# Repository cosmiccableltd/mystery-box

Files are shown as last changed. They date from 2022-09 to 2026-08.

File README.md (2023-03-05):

# Mystery Box

## About
The Mystery Box is a small PCB which provides power ports for various devices to indicate a ringing phone and drive POE devices.
It was designed by [Cosmic Cable Ltd.](http://cosmic.cable.limited) to be used for self-made telephone booths. 

PCB_Overview

## Ports
| Port Name | Function | Usage |
| --- | --- | ----- |
| J1 | [POE](https://en.wikipedia.org/wiki/Power_over_Ethernet) Port | POE powered network device |
| J2 | LAN Port | Connection to external network |
| J3 | Analogue Telephone Port | Connection to external analogue network |
| J4 | Analogue Telephone Port | Connection to analogue telephone |
| X1-1 | +12V | |
| X1-2 |  GND (switched) | swichted on ringing phone line |
| X1-3 | +12V | |
| X1-4 |  GND | |
| X1-5 | +12V | |
| X1-6 |  GND | |
| X1-7 | +12V | |
| X1-8 |  GND | |

## Known Issues
We experienced that the PMV20EN Q2 Mosfet might die from to high current.
It should be changed to something which can handle more current or otherwise it must be ensured that the outgoing power is limited.

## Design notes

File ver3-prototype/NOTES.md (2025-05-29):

- esp32 S3 Zero 
- 12V Buchse 6,3/3.0 + Terminal
- 5-10 feststrom ausgang +
- 5-10 feststrom ausgang -
- 3 geschaltete ausgänge für LED mit N-Kanal-Mosfet (freilaufdiode, pull-down widerstand) IRLZ44N
- DMX ausgang Terminal
- Neopixel ausgang
- POE/RJ45
- optional sicherung am eingang, gesonderter ausgang für o2 Box, Spannungsteiler an ESP für Meldung

- große schraubterminals ohne stecker

pins

DMX 				2x GPIO
Geschaltete Ausgänge 		3x GPIO
Neopixel			2x GPIO

rj45
sicherung + ausgänge + spannungsteiler

länge 4.9mm
breite 6mm

https://learn.adafruit.com/circuitpython-with-esp32-quick-start/command-line-esptool
https://circuitpython.org/board/waveshare_esp32_s3_zero/

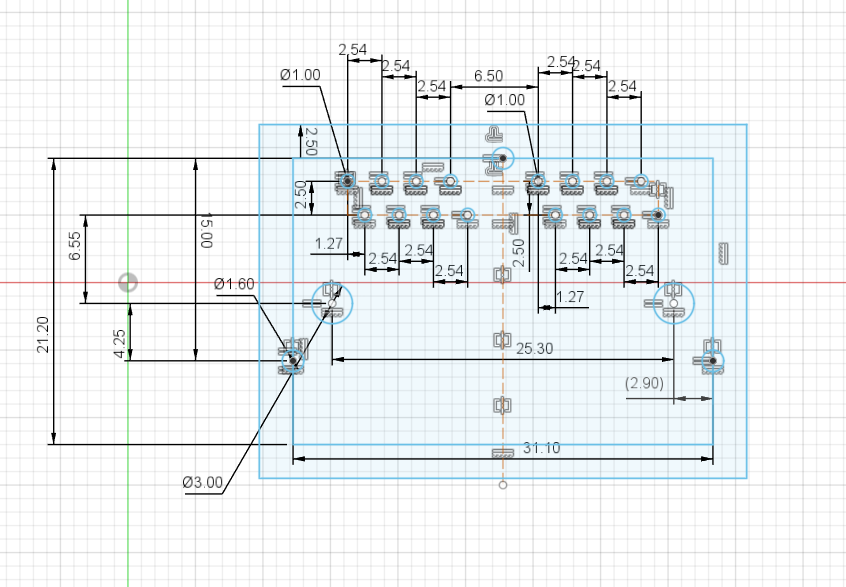
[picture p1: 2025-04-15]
ver3-prototype/Screenshot 2025-04-15 212653.png

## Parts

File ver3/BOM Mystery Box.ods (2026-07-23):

Name | Anzahl | Vorhanden | Bemerkungen | Link
5V Buck Converter | 1 |  |  | https://de.aliexpress.com/item/1005005296570391.html
24V Boost Converter | 1 |  |  | https://de.aliexpress.com/item/1005006381432341.html
Kerko 100nf | 2
Diode groß | 3 |  | Pitch 10,16
Diode klein | 1 |  | Pitch 7,62
Schraubterminal 2-Fach | 17 |  |  | https://de.aliexpress.com/item/1005009002216100.html
Schraubterminal 3-Fach | 4 |  |  | https://de.aliexpress.com/item/1005009002216100.html
XLR-Buchse Female | 1 |  |  | https://de.aliexpress.com/item/1005009831794833.html
ESP32 S3 Zero | 1 |  |  | https://de.aliexpress.com/item/1005007948911104.html
Pin Header | 25
Pin Header Buchse 1x9 | 2 |  |  | https://de.aliexpress.com/item/32970948352.html
Barrel Jack | 1 |  | auf alten platinen | https://www.digikey.de/de/products/detail/same-sky-formerly-cui-devices/PJ-050BH/1644584
RJ45 Doppelbuchse | 1 |  |  | https://de.aliexpress.com/item/1005007077598876.html
LED Blau 3mm | 1
LED Grün 3mm | 1
Neopixel WS2812B | 3
MOSFET IRLZ44N | 3
Widerstand 100 Ohm | 3
Widerstand 1k Ohm | 3
Widerstand 10k Ohm | 3
Smart Switch BV1HD090FJ-C | 1 |  | auf alten platinen | https://www.rohm.de/products/power-management/ipds/smart-high-side-switch-ics/bv1hd090fj-c-product
DMX THVD1400D | 1 |  |  | https://de.aliexpress.com/item/1005009482834248.html
Zylinkerkopfschraube M3x4 | 2
Senkkopfschraube M3x12 | 4
Gehäuse | 1
Deckel | 1
USB-C Kabel | 1 |  |  | https://de.aliexpress.com/item/1005003311183241.html

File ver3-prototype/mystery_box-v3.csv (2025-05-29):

Reference | Value | Footprint | Datasheet | Qty | Qty +ACo- 5
+ACI-12v+AF8-input+AF8-terminal1 | J8 | J9 | J10 | J11 | J12 | J13 | J14 | J15 | J16 | J17 | neopixel+AF8-out1 | neopixel+AF8-pwr1 | switched+AF8-output+AF8-01 | switched+AF8-output+AF8-02 | switched+AF8-output+AF8-03+ACI- | Screw+AF8-Terminal+AF8-01x02 | TerminalBlock:TerminalBlock+AF8-MaiXu+AF8-MX126+AC0-5.0+AC0-02P+AF8-1x02+AF8-P5.00mm | +AH4- | 16 | 80
+ACI-D1 | D2 | D3+ACI- | D | Diode+AF8-THT:D+AF8-DO+AC0-15+AF8-P10.16mm+AF8-Horizontal | +AH4- | 3 | 15
dmx+AF8-out1 | DMX Out | TerminalBlock:TerminalBlock+AF8-MaiXu+AF8-MX126+AC0-5.0+AC0-03P+AF8-1x03+AF8-P5.00mm | +AH4- | 1 | 5
ESP32+AF8-S3 | +AH4- | eigene+AF8-footprints:ESP32+AC0-S3+AC0-Zero |  | 1 | 5
+ACI-J1 | J2 | J3 | J4+ACI- | Conn+AF8-01x02+AF8-Pin | Connector+AF8-PinHeader+AF8-1.00mm:PinHeader+AF8-1x02+AF8-P1.00mm+AF8-Vertical | +AH4- | 4 | 20
J18 | Barrel+AF8-Jack+AF8-MountingPin | eigene+AF8-footprints:CUI+AF8-PJ+AC0-050BH | +AH4- | 1 | 5
J20 | rj45+AC0-CC+AC0-X2+AC0-Aliexpress | eigene+AF8-footprints:RJ45+AF8-X2+AF8-CC+AF8-Aliexpress | +AH4- | 1 | 5
+ACI-Q1 | Q2 | Q3+ACI- | IRLZ44N | Package+AF8-TO+AF8-SOT+AF8-THT:TO+AC0-220+AC0-3+AF8-Vertical | http://www.irf.com/product+AC0-info/datasheets/data/irlz44n.pdf | 3 | 15
+ACI-R1 | R2 | R3+ACI- | R | Resistor+AF8-THT:R+AF8-Axial+AF8-DIN0207+AF8-L6.3mm+AF8-D2.5mm+AF8-P10.16mm+AF8-Horizontal | +AH4- | 3 | 15
U1 | +AH4- | eigene+AF8-footprints:level+AF8-shifter |  | 1 | 5
U2 | MAX485E | eigene+AF8-footprints:max845 modul | https://datasheets.maximintegrated.com/en/ds/MAX1487E+AC0-MAX491E.pdf | 1 | 5
U3 | +AH4- | Package+AF8-SO:SOIC+AC0-8+AF8-3.9x4.9mm+AF8-P1.27mm |  | 1 | 5

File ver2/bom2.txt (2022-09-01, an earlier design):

Partlist

Exported from ver2.brd at 3/28/17 8:25 PM

EAGLE Version 6.6.0 Copyright (c) 1988-2014 CadSoft

Assembly variant: 

Part     Value              Package      Library                 Position (mil)        Orientation

C1       100n 25v           C0805K       rcl                     (918.92495 1325.91216) R0
C4       100n 25v           C0805K       rcl                     (1123.10925 1524.35015) R0
C7       100n 25v           C0805K       rcl                     (783.97183 578.81041) R0

C2       1u 50V             C0805K       rcl                     (968.92495 1525.91216) R0

C3       2u2 50V            C1206K       rcl                     (718.92495 1475.91216) R270
C9       2u2 50V            C1206K       rcl                     (2354.87709 852.59252) R0

C5       10u 16V            C0805K       rcl                     (1418.92495 1075.91216) R180

C6       1u 630V DC         C275-205X316 rcl                     (3425.6122 1598.19808) R270

C10      470u/25V           E3,5-8       rcl                     (1231.07333 707.17938) R180          REICHELT RAD FR 1.000/16

D1       MBRS360            SMC          diode                   (1382.47478 1352.99139) R270         REICHELT MBRS 360 SMD

D2       BZX84CSMD 16V      TO236        diode                   (1924.0689 945.49163) R180

D3       BZX84CSMD          TO236        diode                   (3235.41228 900.07616) R90
D4       BZX84CSMD 20V      TO236        diode                   (3448.09055 902.69254) R270

D5       1N4004             DO41-10      diode                   (3357.73216 735.03543) R180          REICHELT 1N 4007
D6       1N4004             DO41-10      diode                   (3356.86516 611.26833) R0
D7       1N4004             DO41-10      diode                   (3357.72527 493.71395) R180
D8       1N4007             DO41-10      diode                   (3356.79134 353.74508) R0

J1                          215877-4     con-amp                 (147.49422 1512.76956) R270          REICHELT MEBP 8-8S
J2                          215877-4     con-amp                 (147.49422 862.76956) R270
J3                          215876-6     con-amp                 (4264.30106 1402.72625) R90          REICHELT MEBP 6-4S
J4                          215876-6     con-amp                 (4268.68233 850.98068) R90

L1       PIS4728 10u        PIS4728      pis4728                 (1818.92495 1375.91216) R0

LED1                        LED5MM       led                     (852.84584 153.52793) R0             REICHELT LED 5-39000 GN

OK1      4N27M              DIL06        optocoupler             (2731.15527 1140.78962) R90          REICHELT 4N27
PAD1                        3,17/1,3     wirepad                 (2556.01686 146.25234) R0
PAD2                        3,17/1,3     wirepad                 (2395.2201 146.67249) R0

Q1       BSS84              SOT23        transistor-small-signal (2246.26981 1145.81348) R9           REICHELT BSS 84P SMD

Q2       PMV20EN            SOT23        pmv20en                 (2117.93406 1034.52621) R180
Q3       PMV20EN            SOT23        pmv20en                 (782.48376 882.83108) R0
Q4       PMV20EN            SOT23        pmv20en                 (1553.82234 947.54811) R90

R1       267k               R0603        rcl                     (818.92495 1425.91216) R90
R2       R05 RL12T.05JCT-ND R0805        rcl                     (1217.36307 1352.48228) R90
R3       37k4               R0603        rcl                     (1068.92495 1225.91216) R180
R4       9k76               R0603        rcl                     (1068.92495 1325.91216) R0
R5       1M                 R0805        rcl                     (3881.24779 1750.36602) R270
R6       2k2                R1206        rcl                     (3619.24397 902.47527) R0
R7       1M                 R0805        rcl                     (2389.06176 1028.62377) R0
R8       100k               R0805        rcl                     (2379.37758 1148.46752) R90
R9       1k                 R1206        rcl                     (2202.75197 1294.39062) R270
R10      430                R1206        rcl                     (944.13595 701.07505) R90
R11      100                R0603        rcl                     (677.84252 700.66708) R90
R13      1k                 R0805        rcl                     (2239.16265 1002.69968) R90
R14      10k                R0805        rcl                     (1777.88423 925.61368) R90

U$1      LM25011            HVSSOP-10    lm25011                 (1018.92495 1425.91216) R270
U$2      LM5050             SOT-23-6     lm5050                  (782.45042 706.9562)  R0
X1       AKL382-8           ALK382-8     akl382                  (1660.62992 -157.48031) MR0      REICHELT AKL 382 08

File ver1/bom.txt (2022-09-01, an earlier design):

Reichelt:

Count   Art-NO			Comment		Parts
! 3	X7R-G0805 100N		50V rated	C1,C4,C7
! 1	X7R-G0805 1,0/50	50V rated	C2
! 1	X7R-G1206 2,2/50	50V rated	C3
! 1	X5R-G0805 10/16		16V rated	C5
! 1	MKP4-630 1,0µ		630V rated	C6
! 1	TAJ 7343 47/25		25V Tantal	C9
! 1	RAD FC 470/25		25V Elko	C10
! 1	MBRS 360 SMD		Shottky Diode	D1
! 4	1N 4007			Rect Diode	D5-D8
! 2	MEBP 8-8S		RJ45 Buchse	J1,J2
! 2	MEBP 6-4S		RJ11 Buchse	J3,J4
! 1	L-PIS4728 10µ		Spule		L1
! 1	LED 5-39000 GN		LED Gruen	LED1
! 1	4N 27			Optokoppler	OK1
! 1	BSS 84P SMD		PMOS		Q1
! 1	RND 1206 1 2,2K		Widerstand	R6
! 1	RND 1206 1 1,0K		Widerstand	R9
! 1	RND 1206 1 470		Widerstand	R10
! 2	RND 0805 1 1M		Widerstand	R5,R7
! 1	RND 0805 1 100K		Widerstand	R8
! 1	RND 0805 1 1,0K		Widerstand	R13
! 1	RND 0805 1 10k		Widerstand	R14
! 1	RND 0603 1 100		Widerstand	R11
! 1	AKL 382-08		Wannenbuchse	X1
! 1	AKL 369-08		Wannenstecker	X1
! 1	LM 5050MK-1		Diode Ctrl	U$2
! 1	LUM XNES 250		Hohlstecker
! 1	LA 210-5		Zwillingslitze
! 1	1591CFLBK		Gehaeuse

Digikey:
! 1	LM25011 U$1
! 2       BZX84CSMD 20V D3,D4 BZX84C20LT1GOSCT-ND
! 1	  BZX84CSMD 16V D2    BZX84C16FSCT-ND
! 3       PMV20EN Q2,Q3,Q4
! 1       267k               R0603        R1
! 1       37k4               R0603        R3
! 1       9k76               R0603        R4
! 1       R05 RL12T.05JCT-ND R0805        R2

+4 Hohlstecker, Wannenstecker, Gehaeuse
-2 PAD

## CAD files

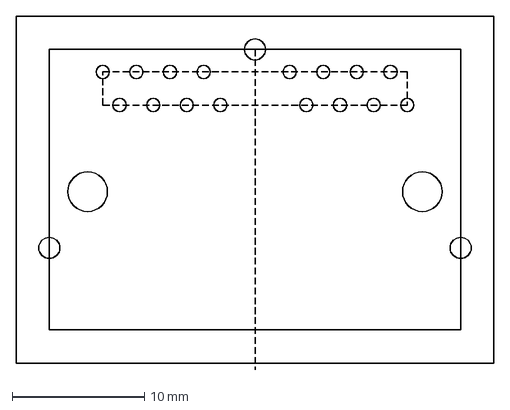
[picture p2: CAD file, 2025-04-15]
ver3-prototype/rj45-footprint.dxf
36.1 x 26.7 mm

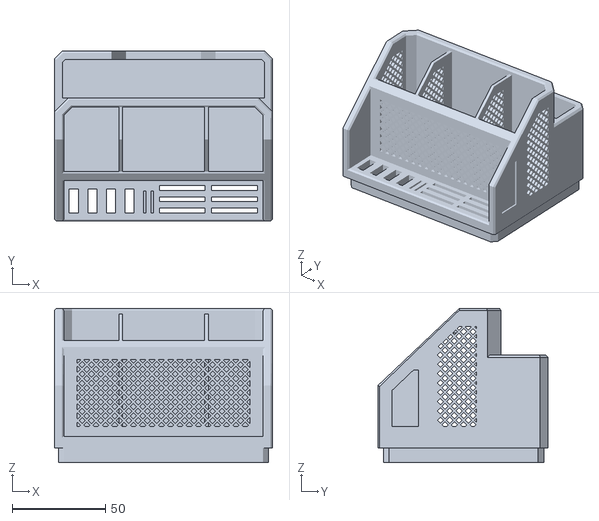
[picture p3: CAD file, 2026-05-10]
ver3/Pencil_Organizer_Wide_Remix.stl
117.0 x 91.5 x 82.7

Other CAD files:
ver3-prototype/rj45-footprint v1.f3d

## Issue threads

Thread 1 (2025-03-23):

Provide schematic (and maybe board?) as PDF.

dronus, 2025-03-23:
Would be cool to have a look into the current state right here without having to download the schematics and run KiCad on them.

Especially useful as KiCad has a quite strict version policy - to open the schematics, a quite fresh version from the last month is needed.

Closed 2025-03-27.

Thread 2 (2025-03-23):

MCU power supply?

dronus, 2025-03-23:
On https://github.com/cosmiccableltd/mystery-box/tree/main/ver3/mystery_box-v3.kicad_sch , the MCU power supply seems missing. The on-board regulators of most ESP32 breakouts don't handle 12V well, so an external regulator (linear or buck) would probably be needed.

Also passing POE power unregulated to the outputs needs guarantees about the provided POE voltage and current capability.

benibr, 2025-03-27:
The idea was to use the power provided via USB from the o2-box for the ESP32, which should be enough.

benibr, 2025-03-27:
Regarding POE: yes this is dangerous POE but the old nanostations expect voltage to "just be there" on the specified lines. They cannot negotiate power supply with 802.3af or similar.
Also this way it's compliant (lol) with the version 2 of the mystery box

Closed 2025-05-28.

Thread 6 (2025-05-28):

Smart switch

benibr, 2025-05-28:
Smart switch should be reevaluated after prototype testing.

If still used:

- [ ] ensure copper connection to OUT pin is thick enough
- [ ] add missing label to Silk Screen

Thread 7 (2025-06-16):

Necessary Improvements after first soldering

benibr, 2025-06-16:
- [ ] Freilaufdioden zu groß für den Platz auf der Plantine. Vorschlag: kleiner Dioden nehmen
- [ ] J1-4 sind viel zu klein
- [ ] USB-C Buchse hat keinen Platz für Stecker
- [ ] Lötpads von Smartswitch ggf. breiter machen zum einfacheren Löten
- [ ] Pinabstand von Levelshifter, komplett falsch, lol
- [ ] Widerstände haben keine Werte
- [ ] Schraubterminal direkt nebeneinander platzieren, damit diese miteinander verbunden werden können (Stabilität)
- [ ] wir haben 10x IRLZ44N gekauft und 5x IRFZ44N. Ist das ein Unterschied?
- [ ] Pins von RJ45 Stecker sind spiegelverkehrt
- [ ] DMX Out 3er Terminal wurde nicht bestellt
- [ ] Clearence beachten zwische   R3 und Verbindung Max485 <-> ESP

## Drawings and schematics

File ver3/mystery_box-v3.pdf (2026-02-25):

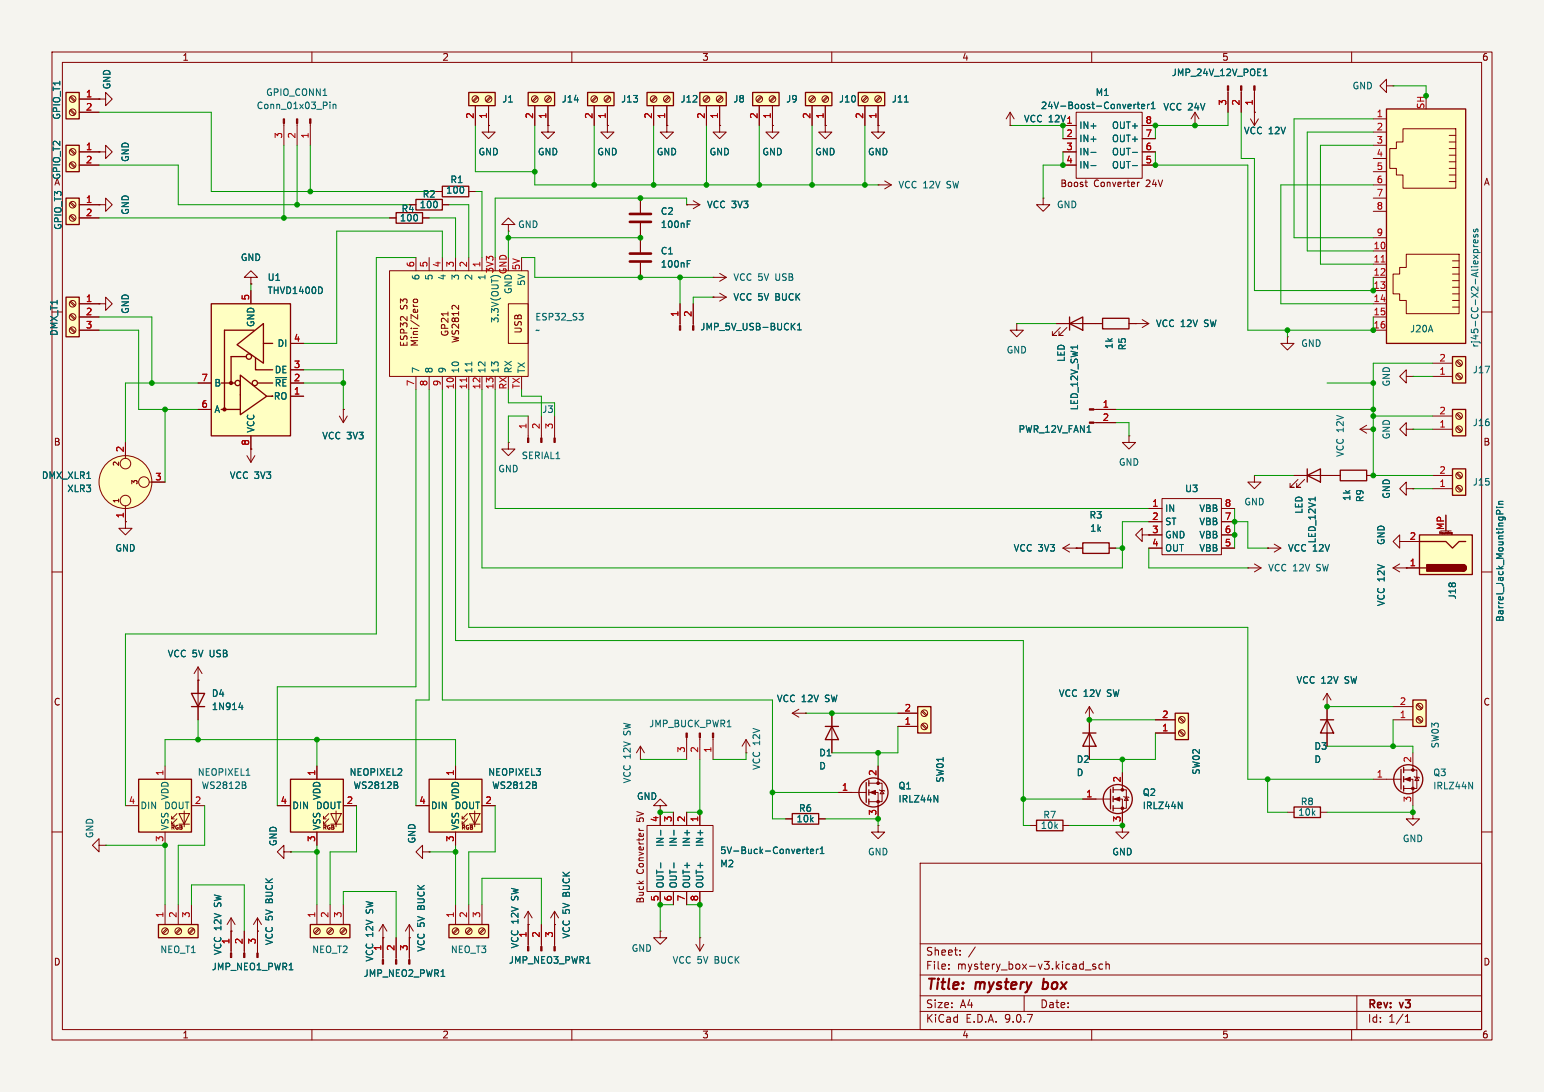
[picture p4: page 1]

7 ESP32_S3 ~ GND GND GND VCC 5V BUCK

VCC 3V3 GND
JMP_5V_USB-BUCK1 VCC 5V USB VCC 12V SW

3 VCC 12V SW VCC 5V BUCK NEOPIXEL2 WS2812B DIN 4 VDD

7 OUT- 6 OUT- 5 NEOPIXEL3 WS2812B DIN 4 VDD

3 DOUT 2 GND GND VCC 12V SW

3 DOUT 2 VCC 12V SW VCC 5V BUCK

Id: 1/1 Title: mystery box

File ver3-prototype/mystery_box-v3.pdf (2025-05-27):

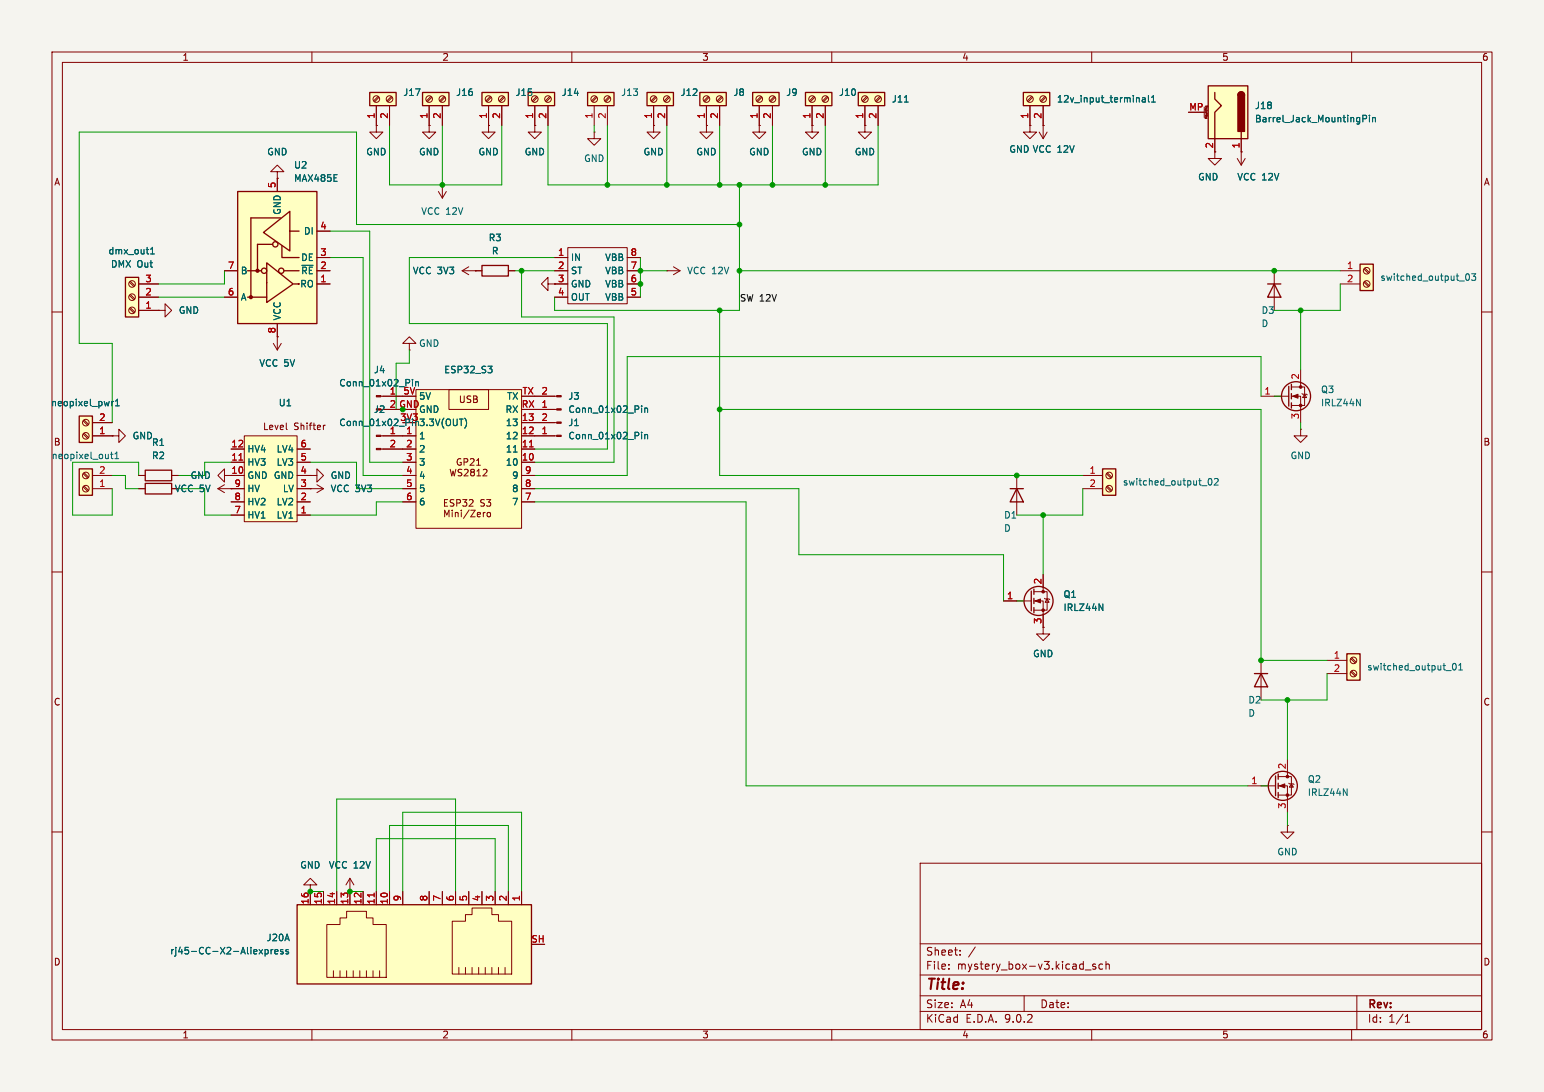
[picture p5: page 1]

Id: 1/1 Title: File: mystery_box-v3.kicad_sch Sheet: /

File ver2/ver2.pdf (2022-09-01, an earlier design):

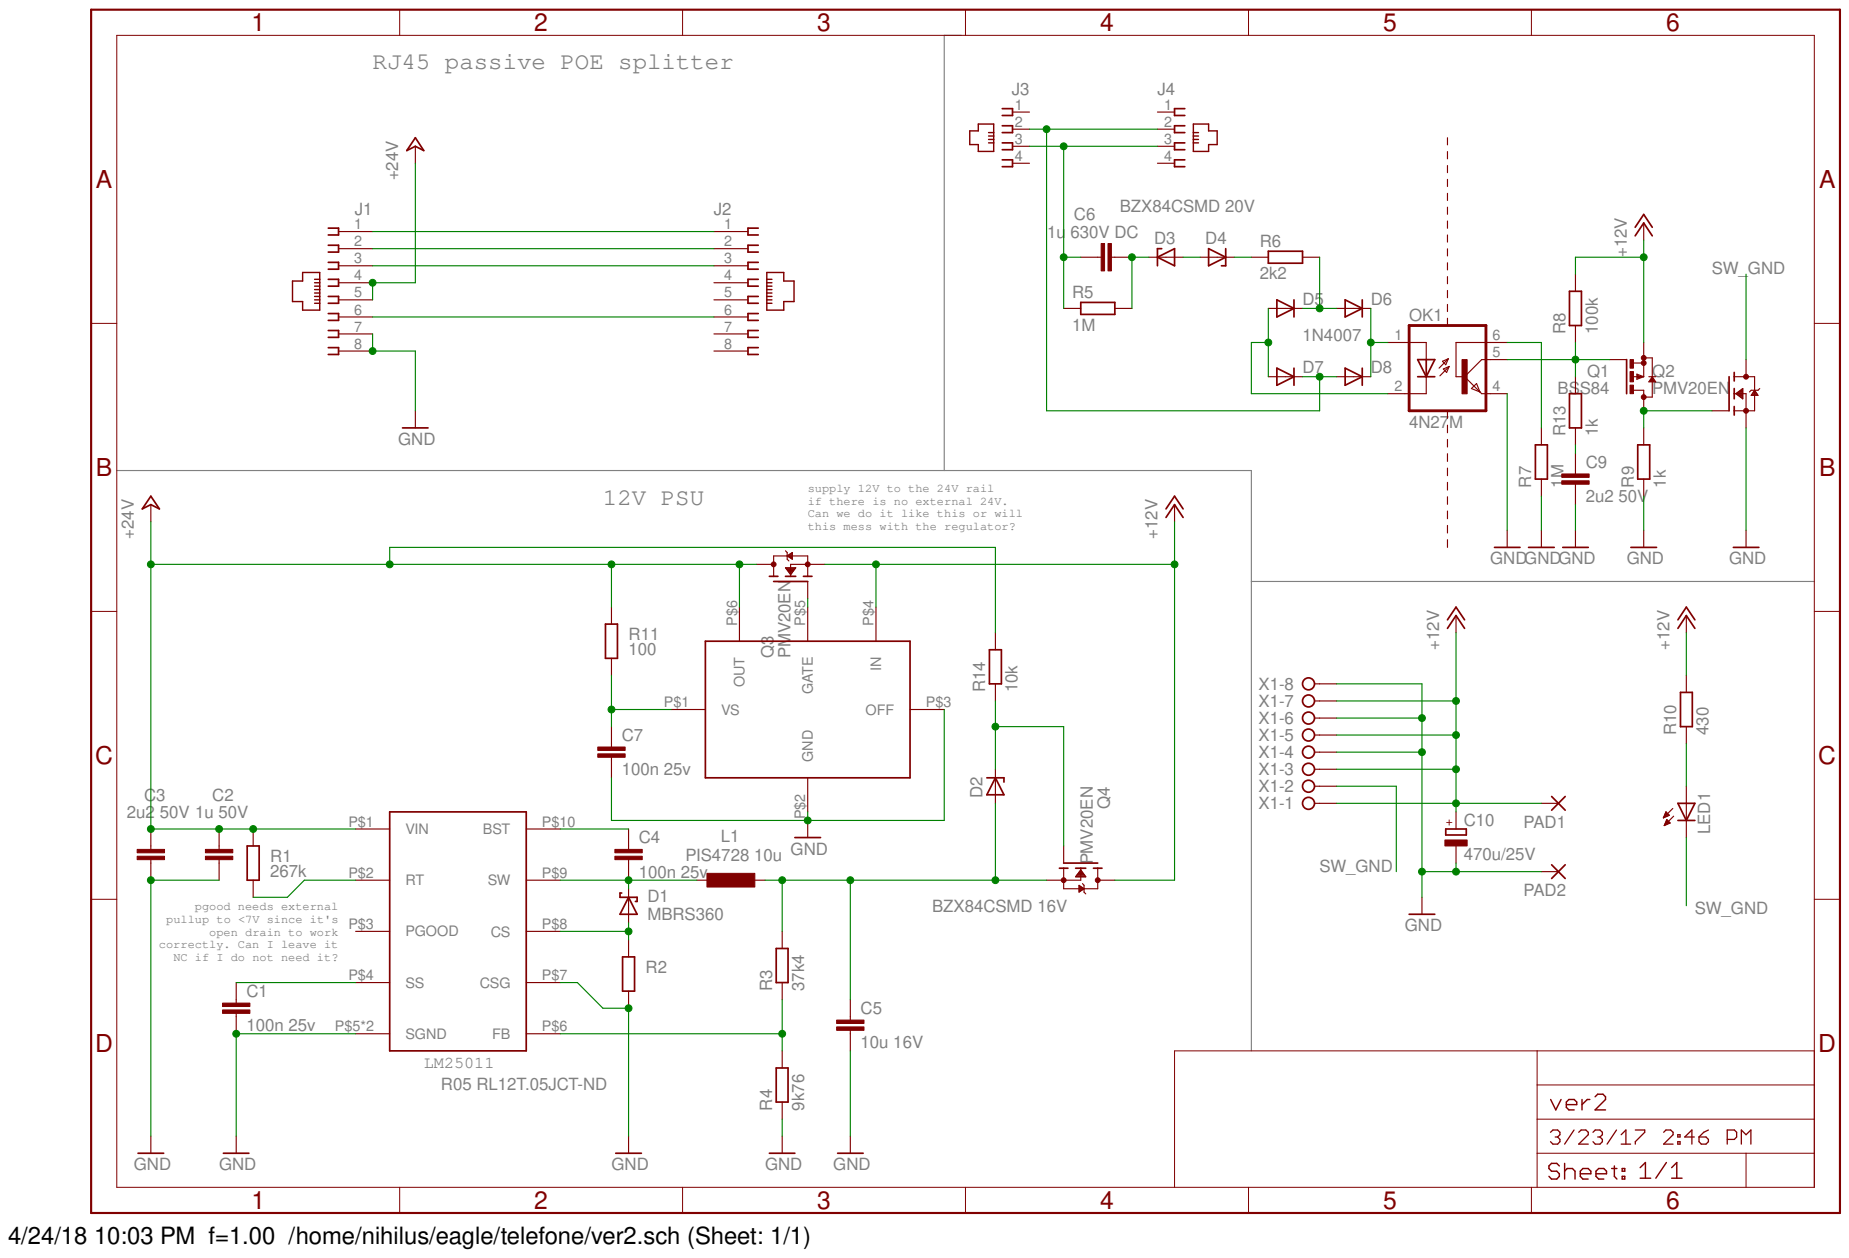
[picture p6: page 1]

this mess with the regulator? 12V PSU

supply 12V to the 24V rail
if there is no external 24V.
Can we do it like this or will

pgood needs external
pullup to <7V since it's

open drain to work

correctly. Can I leave it
NC if I do not need it?

4/24/18 10:03 PM f=1.00 /home/nihilus/eagle/telefone/ver2.sch (Sheet: 1/1)

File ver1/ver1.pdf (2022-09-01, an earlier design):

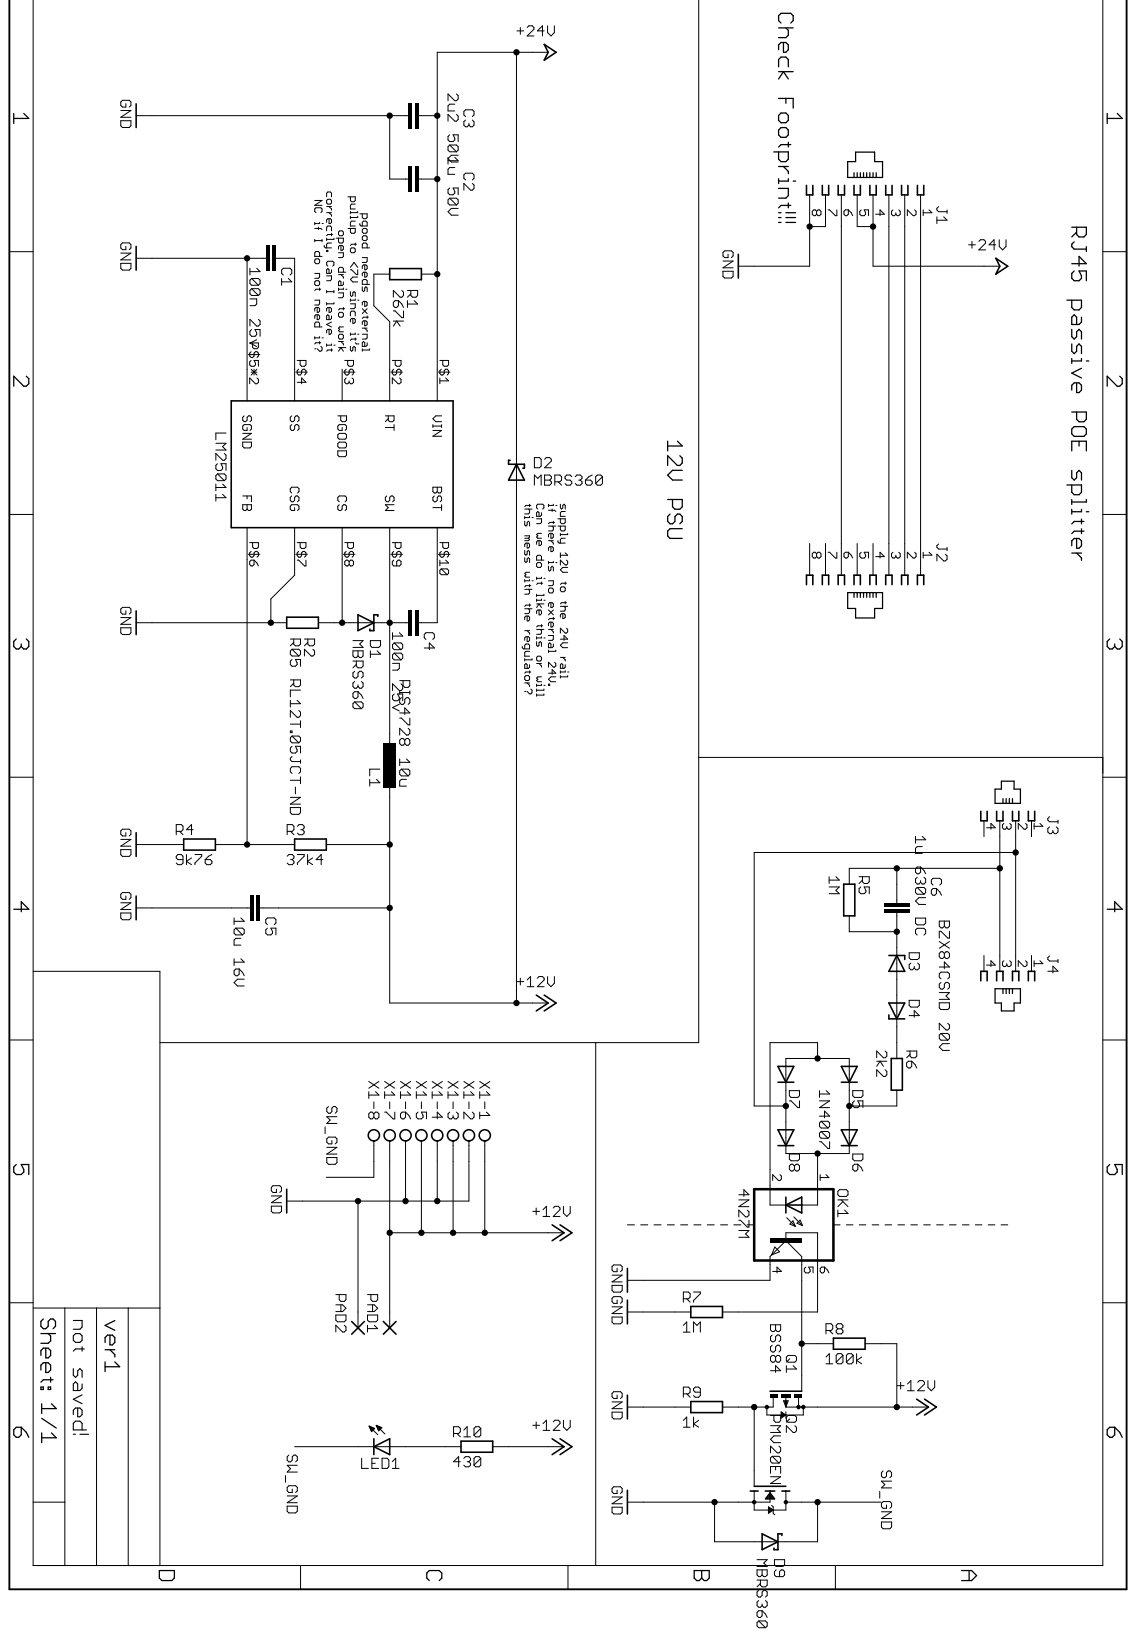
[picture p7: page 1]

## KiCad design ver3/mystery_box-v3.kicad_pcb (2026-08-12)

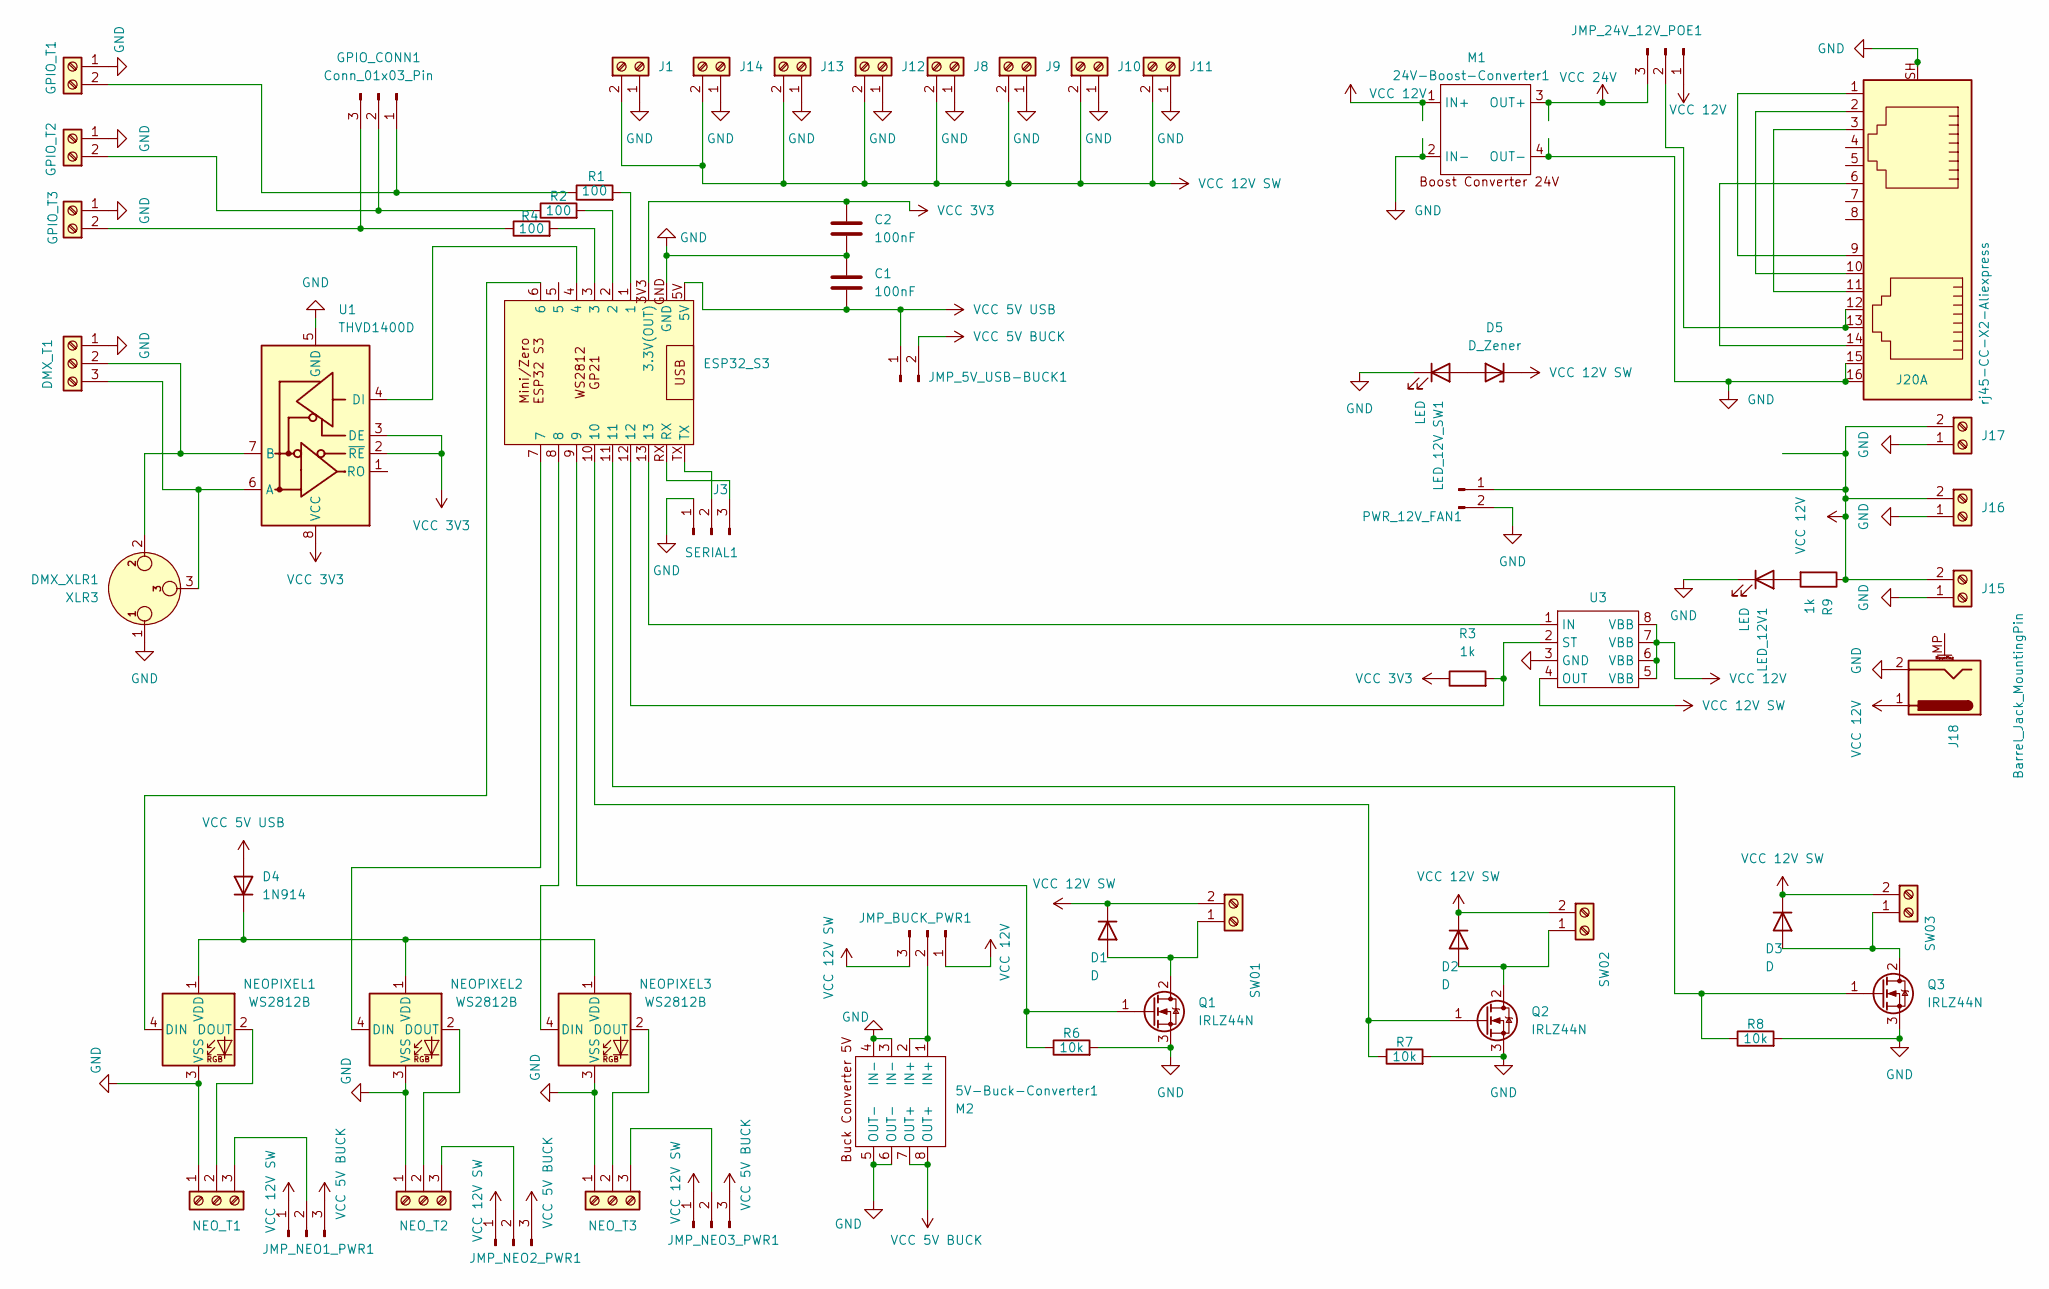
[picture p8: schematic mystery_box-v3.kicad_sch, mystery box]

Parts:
5V-Buck-Converter1: M2; 5V Buck Converter
24V-Boost-Converter1: M1; 24V Boost Converter
C1, C2: 100nF; C_Rect_L7.0mm_W2.5mm_P5.00mm
D1, D2, D3: D; D_DO-15_P10.16mm_Horizontal
D4: 1N914; D_DO-35_SOD27_P7.62mm_Horizontal
D5: D_Zener; D_A-405_P7.62mm_Horizontal
DMX_T1: Screw_Terminal_01x03; TerminalBlock_MaiXu_MX126-5.0-03P_1x03_P5.00mm
DMX_XLR1: XLR3; Jack_XLR_Neutrik_NC3FAAH-0_Horizontal
ESP32_S3: ESP32-S3-Zero
GPIO_CONN1: Conn_01x03_Pin; PinHeader_1x03_P2.54mm_Vertical
GPIO_T1, GPIO_T2, GPIO_T3: Screw_Terminal_01x02; TerminalBlock_MaiXu_MX126-5.0-02P_1x02_P5.00mm
J1, J8, J9, J10, J11, J12, J13, J14, J15, J16, J17: Screw_Terminal_01x02; TerminalBlock_MaiXu_MX126-5.0-02P_1x02_P5.00mm
J3: SERIAL1; PinHeader_1x03_P2.54mm_Vertical
J18: Barrel_Jack_MountingPin; CUI_PJ-050BH
J20: rj45-CC-X2-Aliexpress; RJ45_X2_CC_Aliexpress
JMP_5V_USB-BUCK1: Conn_01x02_Pin; PinHeader_1x02_P2.54mm_Vertical
JMP_24V_12V_POE1: Conn_01x03_Pin; PinHeader_1x03_P2.54mm_Vertical
JMP_BUCK_PWR1: Conn_01x03_Pin; PinHeader_1x03_P2.54mm_Vertical
JMP_NEO1_PWR1, JMP_NEO2_PWR1, JMP_NEO3_PWR1: Conn_01x03_Pin; PinHeader_1x03_P2.54mm_Vertical
LED_12V1, LED_12V_SW1: LED; LED_D3.0mm_Horizontal_O1.27mm_Z2.0mm_Clear
NEOPIXEL1, NEOPIXEL2, NEOPIXEL3: WS2812B; LED_WS2812B_PLCC4_5.0x5.0mm_P3.2mm
NEO_T1, NEO_T2, NEO_T3: Screw_Terminal_01x03; TerminalBlock_MaiXu_MX126-5.0-03P_1x03_P5.00mm
PWR_12V_FAN1: Conn_01x02_Pin; PinHeader_1x02_P2.54mm_Vertical
Q1, Q2, Q3: IRLZ44N; TO-220-3_Vertical
R1, R2, R4: 100; R_Axial_DIN0207_L6.3mm_D2.5mm_P10.16mm_Horizontal
R3, R9: 1k; R_Axial_DIN0207_L6.3mm_D2.5mm_P10.16mm_Horizontal
R6, R7, R8: 10k; R_Axial_DIN0207_L6.3mm_D2.5mm_P10.16mm_Horizontal
SW01, SW02, SW03: Screw_Terminal_01x02; TerminalBlock_MaiXu_MX126-5.0-02P_1x02_P5.00mm
SmartSwitch1: U3; SOIC-8_3.9x4.9mm_P1.27mm
U1: THVD1400D; SOIC-8_3.9x4.9mm_P1.27mm

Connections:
GND: 5V-Buck-Converter1.3 (IN-), 5V-Buck-Converter1.4 (IN-), 5V-Buck-Converter1.5 (OUT-), 5V-Buck-Converter1.6 (OUT-), 24V-Boost-Converter1.2 (IN-), 24V-Boost-Converter1.4 (OUT-), C1.1, C2.2, DMX_T1.1 (Pin_3), DMX_XLR1.1, ESP32_S3.GND, GPIO_T1.1 (Pin_2), GPIO_T2.1 (Pin_2), GPIO_T3.1 (Pin_2), J1.1 (Pin_2), J3.1, J8.1 (Pin_2), J9.1 (Pin_2), J10.1 (Pin_2), J11.1 (Pin_2), J12.1 (Pin_2), J13.1 (Pin_2), J14.1 (Pin_2), J15.1 (Pin_2), J16.1 (Pin_2), J17.1 (Pin_2), J18.2, J20.15, J20.16, J20.SH, LED_12V1.1 (K), LED_12V_SW1.1 (K), NEOPIXEL1.3 (VSS), NEOPIXEL2.3 (VSS), NEOPIXEL3.3 (VSS), NEO_T1.1 (Pin_3), NEO_T2.1 (Pin_3), NEO_T3.1 (Pin_3), PWR_12V_FAN1.2, Q1.3 (S), Q2.3 (S), Q3.3 (S), R6.2, R7.2, R8.2, SmartSwitch1.3 (GND), U1.5 (GND)
unnamed: D1.2 (A), Q1.2 (D), SW01.1 (Pin_2)
unnamed: D2.2 (A), Q2.2 (D), SW02.1 (Pin_2)
unnamed: D3.2 (A), Q3.2 (D), SW03.1 (Pin_2)
unnamed: D4.1 (K), NEOPIXEL1.1 (VDD), NEOPIXEL2.1 (VDD), NEOPIXEL3.1 (VDD)
unnamed: D5.2 (A), LED_12V_SW1.2 (A)
unnamed: DMX_T1.3 (Pin_1), DMX_XLR1.3, U1.6 (A)
unnamed: DMX_T1.2, DMX_XLR1.2, U1.7 (B)
unnamed: ESP32_S3.1, R1.2
unnamed: ESP32_S3.2, R2.2
unnamed: ESP32_S3.3, R4.2
unnamed: GPIO_CONN1.1, GPIO_T1.2 (Pin_1), R1.1
unnamed: GPIO_CONN1.2, GPIO_T2.2 (Pin_1), R2.1
unnamed: GPIO_CONN1.3, GPIO_T3.2 (Pin_1), R4.1
unnamed: ESP32_S3.TX, J3.2
unnamed: ESP32_S3.RX, J3.3
unnamed: J20.1, J20.9
unnamed: J20.2, J20.10
unnamed: J20.3, J20.11
unnamed: J20.6, J20.14
unnamed 20: J20.12, J20.13, JMP_24V_12V_POE1.2; also elsewhere on the board
unnamed: 5V-Buck-Converter1.1 (IN+), 5V-Buck-Converter1.2 (IN+), JMP_BUCK_PWR1.2
unnamed: JMP_NEO1_PWR1.2, NEO_T1.3 (Pin_1)
unnamed: JMP_NEO2_PWR1.2, NEO_T2.3 (Pin_1)
unnamed: JMP_NEO3_PWR1.2, NEO_T3.3 (Pin_1)
unnamed: LED_12V1.2 (A), R9.2
unnamed: ESP32_S3.6, NEOPIXEL1.4 (DIN)
unnamed: NEOPIXEL1.2 (DOUT), NEO_T1.2
unnamed: ESP32_S3.7, NEOPIXEL2.4 (DIN)
unnamed: NEOPIXEL2.2 (DOUT), NEO_T2.2
unnamed: ESP32_S3.8, NEOPIXEL3.4 (DIN)
unnamed: NEOPIXEL3.2 (DOUT), NEO_T3.2
unnamed: ESP32_S3.9, Q1.1 (G), R6.1
unnamed: ESP32_S3.10, Q2.1 (G), R7.1
unnamed: ESP32_S3.11, Q3.1 (G), R8.1
unnamed: ESP32_S3.13, SmartSwitch1.1 (IN)
unnamed: ESP32_S3.12, R3.2, SmartSwitch1.2 (ST)
unnamed: ESP32_S3.4, U1.4 (DI)
VCC 3V3: C2.1, ESP32_S3.3V3 (3.3V(OUT)), R3.1, U1.2 (~RE), U1.3 (DE), U1.8 (VCC)
VCC 5V BUCK: 5V-Buck-Converter1.7 (OUT+), 5V-Buck-Converter1.8 (OUT+), JMP_5V_USB-BUCK1.2, JMP_NEO1_PWR1.3, JMP_NEO2_PWR1.3, JMP_NEO3_PWR1.3
VCC 5V USB: C1.2, D4.2 (A), ESP32_S3.5V, JMP_5V_USB-BUCK1.1
VCC 12V: 24V-Boost-Converter1.1 (IN+), J15.2 (Pin_1), J16.2 (Pin_1), J17.2 (Pin_1), J18.1, JMP_24V_12V_POE1.1, JMP_BUCK_PWR1.1, PWR_12V_FAN1.1, R9.1, SmartSwitch1.5 (VBB), SmartSwitch1.6 (VBB), SmartSwitch1.7 (VBB), SmartSwitch1.8 (VBB); also elsewhere on the board
VCC 12V SW: D1.1 (K), D2.1 (K), D3.1 (K), D5.1 (K), J1.2 (Pin_1), J8.2 (Pin_1), J9.2 (Pin_1), J10.2 (Pin_1), J11.2 (Pin_1), J12.2 (Pin_1), J13.2 (Pin_1), J14.2 (Pin_1), JMP_BUCK_PWR1.3, JMP_NEO1_PWR1.1, JMP_NEO2_PWR1.1, JMP_NEO3_PWR1.1, SW01.2 (Pin_1), SW02.2 (Pin_1), SW03.2 (Pin_1), SmartSwitch1.4 (OUT)
VCC 24V: 24V-Boost-Converter1.3 (OUT+), JMP_24V_12V_POE1.3; also elsewhere on the board

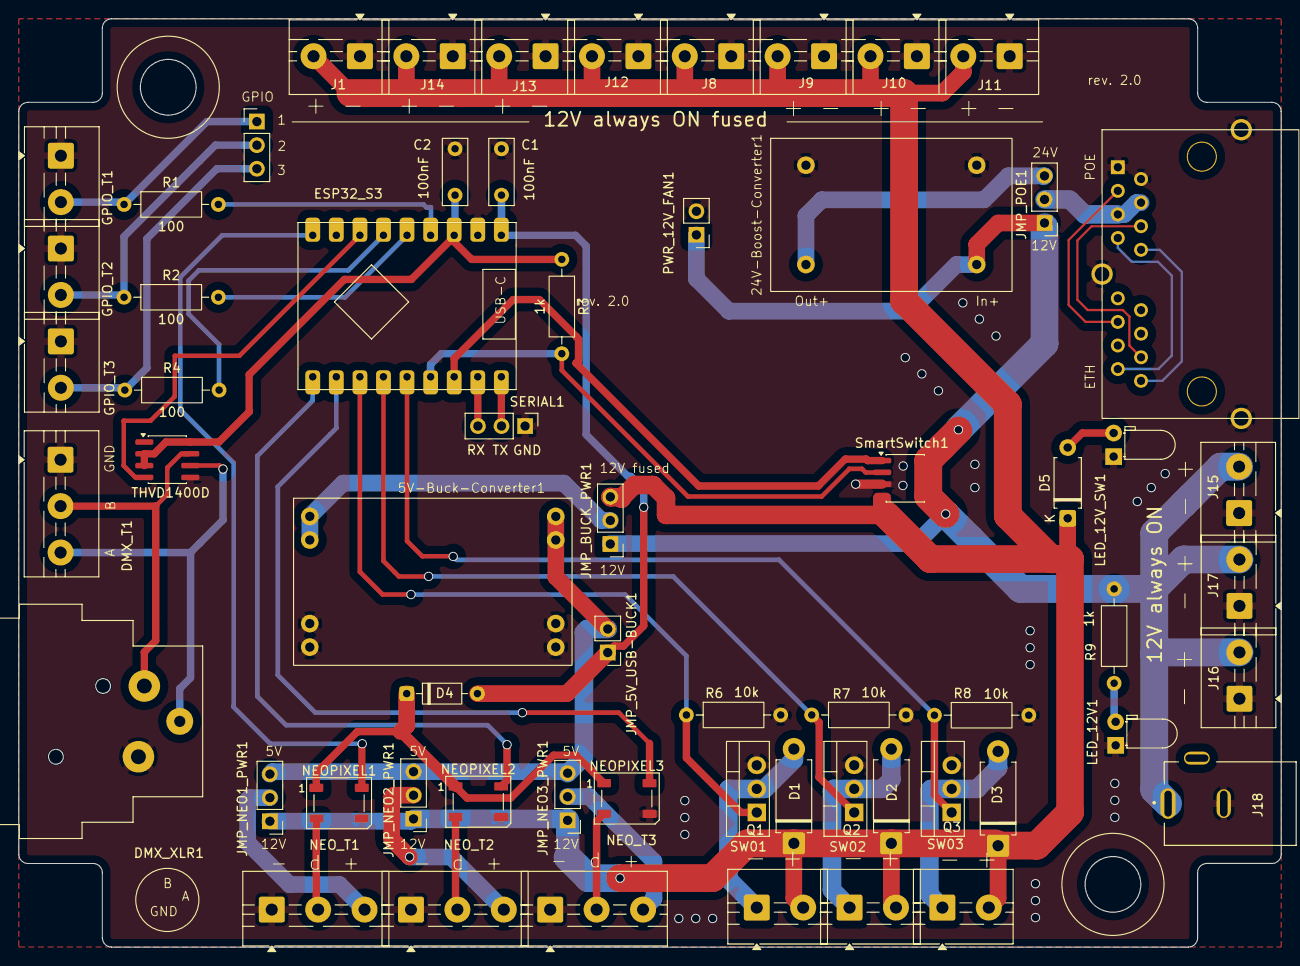
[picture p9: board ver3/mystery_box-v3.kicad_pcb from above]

Board: 2 copper layers, 136.0 x 100.0 mm, 61 parts (0 on the bottom side), 44 nets.

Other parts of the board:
JMP_POE1: Conn_01x03_Pin; PinHeader_1x03_P2.54mm_Vertical

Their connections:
unnamed 20: JMP_POE1.2; also elsewhere on the board
VCC 12V: JMP_POE1.1; also elsewhere on the board
VCC 24V: JMP_POE1.3; also elsewhere on the board

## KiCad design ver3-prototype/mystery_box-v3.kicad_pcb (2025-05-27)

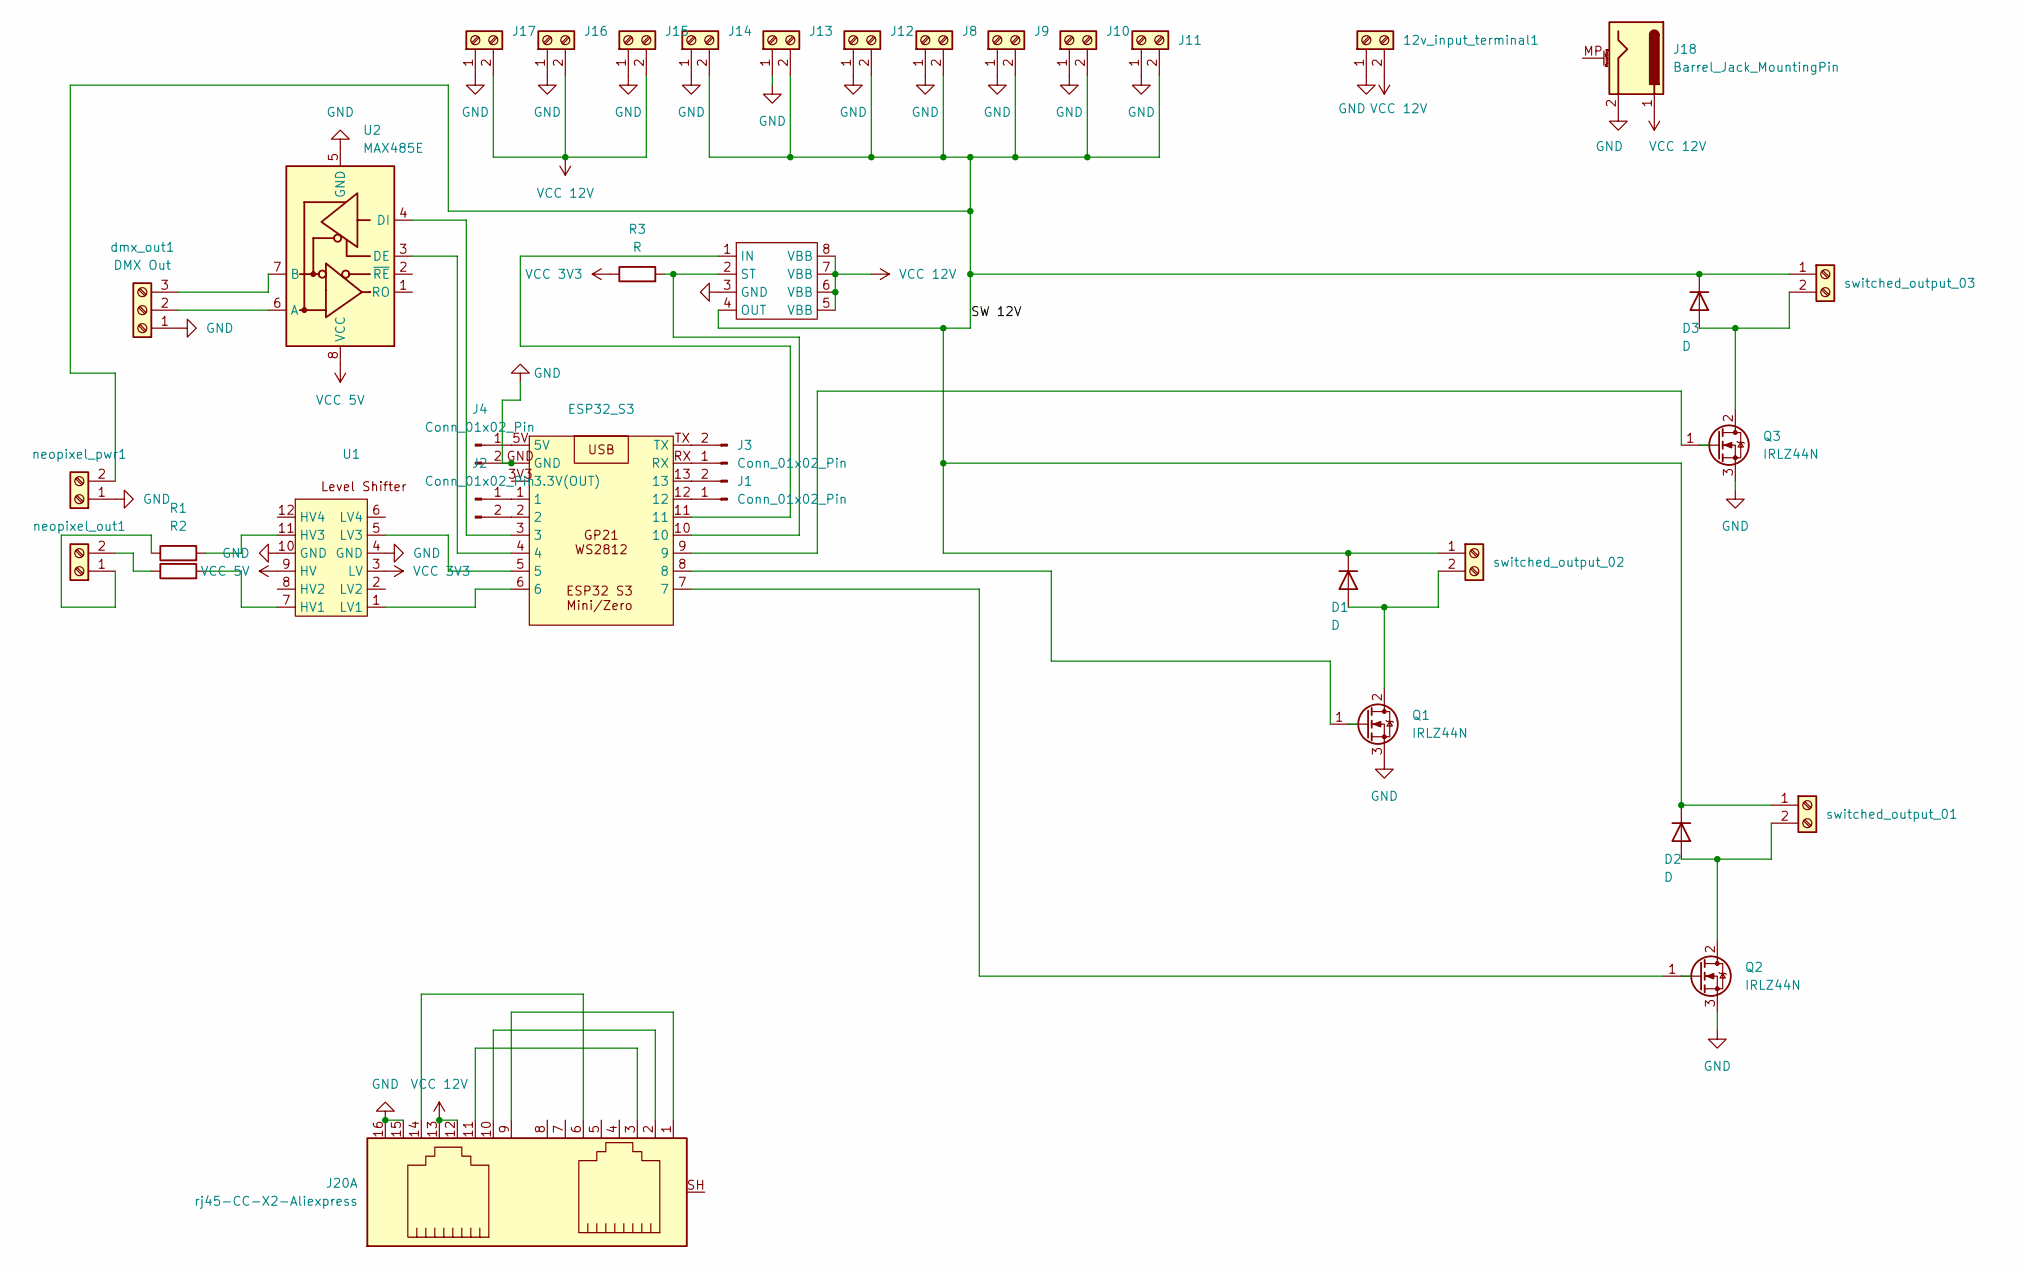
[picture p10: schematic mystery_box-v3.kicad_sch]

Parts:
12v_input_terminal1: Screw_Terminal_01x02; TerminalBlock_MaiXu_MX126-5.0-02P_1x02_P5.00mm
D1, D2, D3: D; D_DO-15_P10.16mm_Horizontal
ESP32_S3: ESP32-S3-Zero
J1, J2, J3, J4: Conn_01x02_Pin; PinHeader_1x02_P1.00mm_Vertical
J8, J9, J10, J11, J12, J13, J14, J15, J16, J17: Screw_Terminal_01x02; TerminalBlock_MaiXu_MX126-5.0-02P_1x02_P5.00mm
J18: Barrel_Jack_MountingPin; CUI_PJ-050BH
J20: rj45-CC-X2-Aliexpress; RJ45_X2_CC_Aliexpress
Q1, Q2, Q3: IRLZ44N; TO-220-3_Vertical
R1, R2, R3: R; R_Axial_DIN0207_L6.3mm_D2.5mm_P10.16mm_Horizontal
U1: level_shifter
U2: MAX485E; max845 modul
U3: SOIC-8_3.9x4.9mm_P1.27mm
dmx_out1: DMX Out; TerminalBlock_MaiXu_MX126-5.0-03P_1x03_P5.00mm
neopixel_out1: Screw_Terminal_01x02; TerminalBlock_MaiXu_MX126-5.0-02P_1x02_P5.00mm
neopixel_pwr1: Screw_Terminal_01x02; TerminalBlock_MaiXu_MX126-5.0-02P_1x02_P5.00mm
switched_output_01, switched_output_02, switched_output_03: Screw_Terminal_01x02; TerminalBlock_MaiXu_MX126-5.0-02P_1x02_P5.00mm

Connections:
/SW 12V: D1.1 (K), D2.1 (K), D3.1 (K), J8.2, J9.2, J10.2, J11.2, J12.2, J13.2, J14.2, U3.4 (OUT), neopixel_pwr1.2, switched_output_01.1, switched_output_02.1, switched_output_03.1; also elsewhere on the board
GND: 12v_input_terminal1.1, ESP32_S3.GND, J4.2, J8.1, J9.1, J10.1, J11.1, J12.1, J13.1, J14.1, J15.1, J16.1, J17.1, J18.2, J20.15, J20.16, Q1.3 (S), Q2.3 (S), Q3.3 (S), U1.4 (GND), U1.10 (GND), U2.5 (GND), U3.3 (GND), dmx_out1.1, neopixel_pwr1.1; also elsewhere on the board
unnamed: D1.2 (A), Q1.2 (D), switched_output_02.2
unnamed: D2.2 (A), Q2.2 (D), switched_output_01.2
unnamed: D3.2 (A), Q3.2 (D), switched_output_03.2
unnamed: ESP32_S3.12, J1.1
unnamed: ESP32_S3.13, J1.2
unnamed: ESP32_S3.1, J2.1
unnamed: ESP32_S3.2, J2.2
unnamed: ESP32_S3.RX, J3.1
unnamed: ESP32_S3.TX, J3.2
unnamed: ESP32_S3.5V, J4.1
unnamed: J20.1, J20.9
unnamed: J20.2, J20.10
unnamed: J20.3, J20.11
unnamed: J20.6, J20.14
unnamed: ESP32_S3.8, Q1.1 (G)
unnamed: ESP32_S3.7, Q2.1 (G)
unnamed: ESP32_S3.9, Q3.1 (G)
unnamed: R2.2, U1.7 (HV1)
unnamed: R1.2, U1.11 (HV3)
unnamed: ESP32_S3.6, U1.1 (LV1)
unnamed: ESP32_S3.5, U1.5 (LV3)
unnamed: U2.6 (A), dmx_out1.2
unnamed: U2.7 (B), dmx_out1.3
unnamed: ESP32_S3.4, U2.3 (DE)
unnamed: ESP32_S3.3, U2.4 (DI)
unnamed: ESP32_S3.11, U3.1 (IN)
unnamed: ESP32_S3.10, R3.2, U3.2 (ST)
unnamed: R1.1, neopixel_out1.1
unnamed: R2.1, neopixel_out1.2
VCC 3V3: R3.1, U1.3 (LV)
VCC 5V: U1.9 (HV), U2.8 (VCC)
VCC 12V: 12v_input_terminal1.2, J15.2, J16.2, J17.2, J18.1, J20.12, J20.13, U3.5 (VBB), U3.6 (VBB), U3.7 (VBB), U3.8 (VBB)

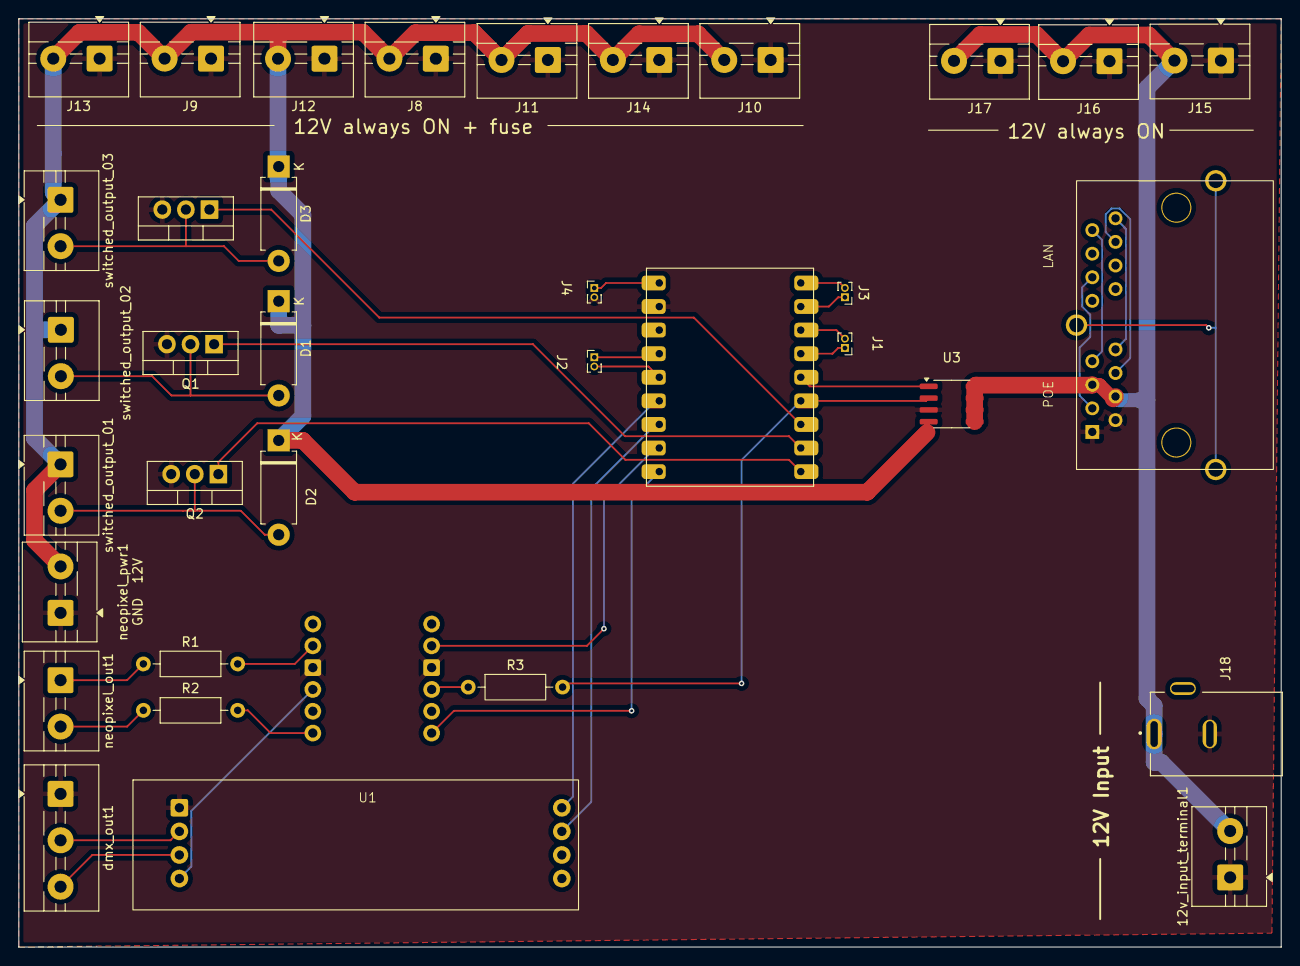
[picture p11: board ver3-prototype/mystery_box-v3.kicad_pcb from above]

Board: 2 copper layers, 136.0 x 100.0 mm, 36 parts (0 on the bottom side), 34 nets.

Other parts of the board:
neopixel_pwr1
GND  12V: Screw_Terminal_01x02; TerminalBlock_MaiXu_MX126-5.0-02P_1x02_P5.00mm

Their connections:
/SW 12V: neopixel_pwr1 GND 12V.2; also elsewhere on the board
GND: neopixel_pwr1 GND 12V.1; also elsewhere on the board

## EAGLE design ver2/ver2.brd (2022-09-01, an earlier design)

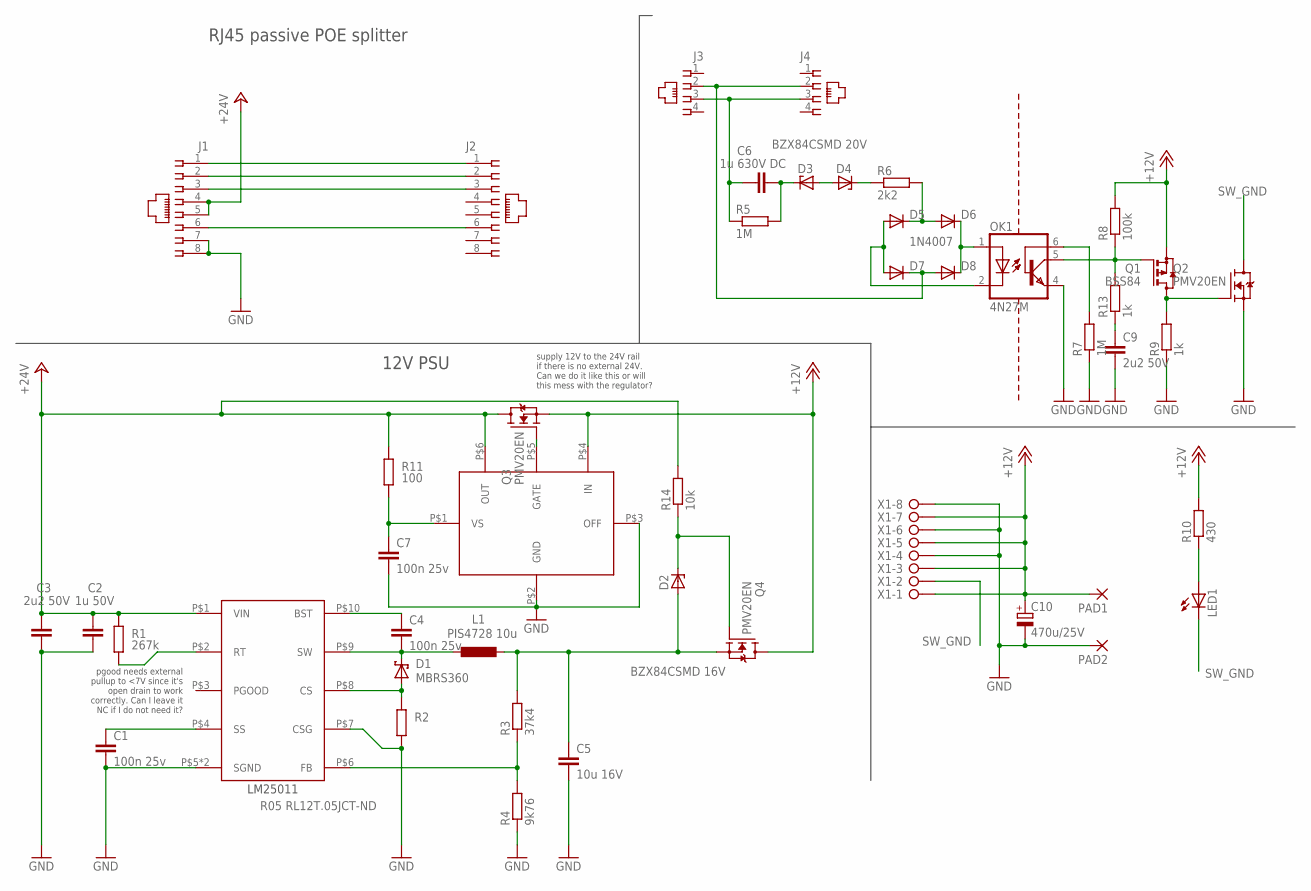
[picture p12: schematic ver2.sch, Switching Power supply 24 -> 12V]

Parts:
C1, C4, C7: 100n 25v; C0805K
C2: 1u 50V; C0805K
C3, C9: 2u2 50V; C1206K
C5: 10u 16V; C0805K
C6: 1u 630V DC; C275-205X316
C10: 470u/25V; E3,5-8
D1: MBRS360; SMC
D2: BZX84CSMD 16V; TO236
D3: BZX84CSMD; TO236
D4: BZX84CSMD 20V; TO236
D5, D6, D7: 1N4004; DO41-10
D8: 1N4007; DO41-10
J1, J2: 215877-4
J3, J4: 215876-6
L1: PIS4728 10u; PIS4728
LED1: LED5MM
OK1: 4N27M; DIL06
PAD1, PAD2: 3,17/1,3
Q1: BSS84; SOT23
Q2, Q3, Q4: PMV20EN; SOT23
R1: 267k; R0603
R2: R05 RL12T.05JCT-ND; R0805
R3: 37k4; R0603
R4: 9k76; R0603
R5, R7: 1M; R0805
R6: 2k2; R1206
R8: 100k; R0805
R9: 1k; R1206
R10: 430; R1206
R11: 100; R0603
R13: 1k; R0805
R14: 10k; R0805
U$1: LM25011; HVSSOP-10
U$2: LM5050; SOT-23-6
X1: AKL382-8; ALK382-8

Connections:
+12V: C10.+, PAD1.1, Q1.2 (S), Q3.2 (S), Q4.3 (D), R8.2, R10.2, U$2.P$4 (IN), X1.P$1, X1.P$3, X1.P$5, X1.P$7
+24V: C2.1, C3.1, J1.4, J1.5, Q3.3 (D), R1.2, R11.2, R14.2, U$1.P$1 (VIN), U$2.P$6 (OUT)
EHT1_N: J1.2, J2.2
EHT1_P: J1.1, J2.1
ETH2_N: J1.6, J2.6
ETH2_P: J1.3, J2.3
GND: C1.2, C2.2, C3.2, C5.2, C7.2, C9.2, C10.-, J1.7, J1.8, OK1.4 (EMI), PAD2.1, Q2.2 (S), R2.1, R4.1, R7.1, R9.1, U$1.P$5 (SGND), U$1.P$7 (CSG), U$1.P$11 (SGND), U$2.P$2 (GND), U$2.P$3 (OFF), X1.P$4, X1.P$6, X1.P$8
unnamed: C1.1, U$1.P$4 (SS)
unnamed: D1.A, R2.2, U$1.P$8 (CS)
unnamed: R1.1, U$1.P$2 (RT)
unnamed: D7.C, D8.A, J3.2, J4.2
unnamed: C4.2, D1.C, L1.P$1 (1), U$1.P$9 (SW)
unnamed: C4.1, U$1.P$10 (BST)
unnamed: R3.1, R4.2, U$1.P$6 (FB)
unnamed: C6.1, J3.3, J4.3, R5.1
unnamed: C6.2, D3.C, R5.2
unnamed: D3.A, D4.A
unnamed: D4.C, R6.1
unnamed: D5.C, D6.A, R6.2
unnamed: D5.A, D7.A, OK1.2 (C)
unnamed: D6.C, D8.C, OK1.1 (A)
unnamed: Q1.3 (D), Q2.1 (G), R9.2
unnamed: OK1.6 (BAS), R7.2
unnamed: LED1.A, R10.1
unnamed: C7.1, R11.1, U$2.P$1 (VS)
unnamed: Q3.1 (G), U$2.P$5 (GATE)
unnamed: C5.1, D2.A, L1.P$2 (2), Q4.2 (S), R3.2
unnamed: D2.C, Q4.1 (G), R14.1
unnamed: C9.1, R13.1
OK_OUT: OK1.5 (COL), Q1.1 (G), R8.1, R13.2
SW_GND: LED1.K (C), Q2.3 (D), X1.P$2

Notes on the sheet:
pgood needs external pullup to <7V since it's open drain to work correctly. Can I leave it NC if I do not need it?
supply 12V to the 24V rail if there is no external 24V. Can we do it like this or will this mess with the regulator?
12V PSU
RJ45 passive POE splitter
LM25011

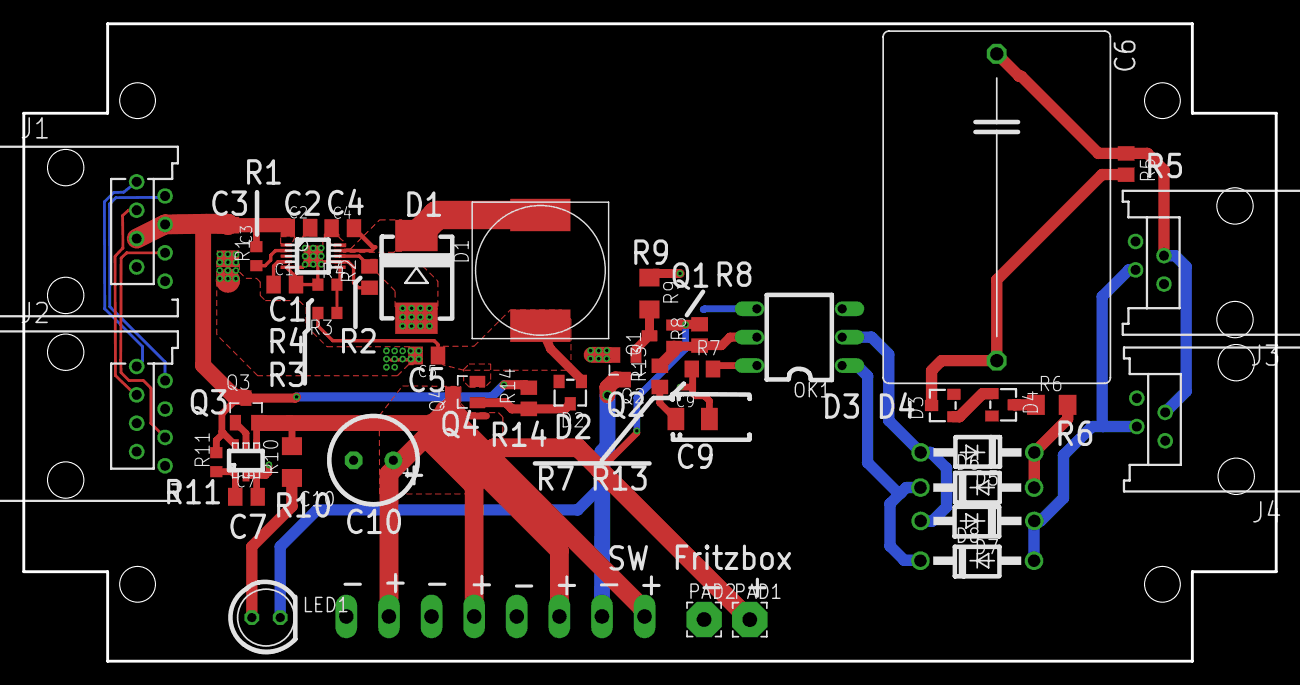
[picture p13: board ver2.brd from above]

Board: 2 copper layers, 112.0 x 57.0 mm, 46 parts (1 on the bottom side), 31 nets.

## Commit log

2022-09-01 added ver1
    [ver1.GBL, ver1.GBO, ver1.GBP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]
2022-09-01 added ver2
    [ver2.brd, ver2.sch]
2025-02-25 added first draft v3
    [mystery_box-v3.kicad_pcb, mystery_box-v3.kicad_sch]
2025-02-25 first draft v3
    [mystery_box-v3.kicad_sch]
2025-03-05 update 2. meeting
    [mystery_box-v3.kicad_sch]
2025-03-27 Added current PDF
2025-04-15 added footprints for rj45, max485 module
    [mystery_box-v3.kicad_sch, rj45-footprint v1.f3d, rj45-footprint.dxf]
2025-04-15 kikad symbol and footprint libraries
2025-05-06 pcb editor beginning
    [mystery_box-v3.kicad_pcb, mystery_box-v3.kicad_sch]
2025-05-07 enabled pipeline for pcb
2025-05-20 smart switch
    [mystery_box-v3.kicad_pcb, mystery_box-v3.kicad_sch]
2025-05-27 final prototype v3
    [freerouting.dsn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]
2025-05-29 added notes
    [mystery_box-v3.csv]
2025-11-05 first edit of serious ver3
    [freerouting.dsn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]
2025-11-18 schematic with converter + footprints
    [freerouting.dsn, mystery_box-v3.kicad_pcb, mystery_box-v3.kicad_sch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]
2025-11-25 renamed ver3-prototype
    [freerouting.dsn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]
2025-11-25 beginning ver3 PCB
    [mystery_box-v3-B_Cu.gbr, mystery_box-v3-B_Mask.gbr, mystery_box-v3-B_Silkscreen.gbr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]
2025-12-02 readded DMX
    [mystery_box-v3.kicad_sch]
2025-12-02 ver3: first PCB layout
    [mystery_box-v3.kicad_pcb, mystery_box-v3.kicad_sch]
2026-01-13 beginning ver3 PCB routing
    [mystery_box-v3.kicad_pcb, mystery_box-v3.kicad_sch]
2026-02-04 v3: first draft finished
    [mystery_box-v3.kicad_pcb]
2026-02-10 logo + silk stuff
    [mystery_box-v3.kicad_pcb, mystery_box-v3.kicad_sch]
2026-02-17 ver3: added GND to serial1
    [mystery_box-v3.kicad_pcb, mystery_box-v3.kicad_sch]
2026-02-17 ver3: RJ45 data routing on same side
    [mystery_box-v3.kicad_pcb]
2026-02-18 ver3: silkscreen beaty & 12v fused LED
    [mystery_box-v3.kicad_pcb, mystery_box-v3.kicad_sch]
2026-02-25 removed old stuff
    [mystery_box-v3-NPTH.drl, mystery_box-v3-PTH.drl, mystery_box-v3-job.gbrjob]
2026-02-25 mounting holes rework
    [mystery_box-v3.csv, mystery_box-v3.kicad_pcb]
2026-02-25 added BOM
    [BOM Mystery Box.ods]
2026-02-25 updated BOM
    [BOM Mystery Box.ods]
2026-02-25 fixed SmartSwitch Pad
    [mystery_box-v3.kicad_pcb]
2026-02-25 ver3: fab outputs
    [mystery_box-v3-B_Cu.gbr, mystery_box-v3-B_Mask.gbr, mystery_box-v3-B_Silkscreen.gbr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]
2026-07-23 minor changed to BOM
    [BOM Mystery Box.ods]
2026-07-25 ver3 rev 2.0 prep for at.\tension
    [mystery_box-v3.kicad_pcb, mystery_box-v3.kicad_sch]
2026-08-07 new 24v boost converter module
    [mystery_box-v3.kicad_pcb, mystery_box-v3.kicad_sch]
2026-08-12 ver3: moved boost converter to designated place
    [mystery_box-v3.kicad_pcb]
2026-08-12 ver3: minor fixups of vias
    [mystery_box-v3.kicad_pcb]
2026-08-12 ver3: better POE JMP hints
    [mystery_box-v3.kicad_pcb]
2026-08-12 ver3: rev 2.0 fab output
    [mystery_box-v3-B_Cu.gbr, mystery_box-v3-B_Mask.gbr, mystery_box-v3-B_Silkscreen.gbr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]
